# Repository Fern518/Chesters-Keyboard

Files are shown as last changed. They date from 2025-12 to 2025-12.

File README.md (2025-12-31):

# Chester's Keyboard
A custom TKL keyboard built for the *Hack Club Blueprint program*.

It functions as a miniature media dashboard: the display shows the current track (TO BE IMPLEMENTED), the knob controls volume, and the six keys can be bound to any shortcut.

## The Keyboard
Everything fits together using 4 M3 Bolts and Heatset inserts, one in each corner. 

It has 2 separate printed pieces. The base, where the PCB sits, and the top cover, which protects the PCB.

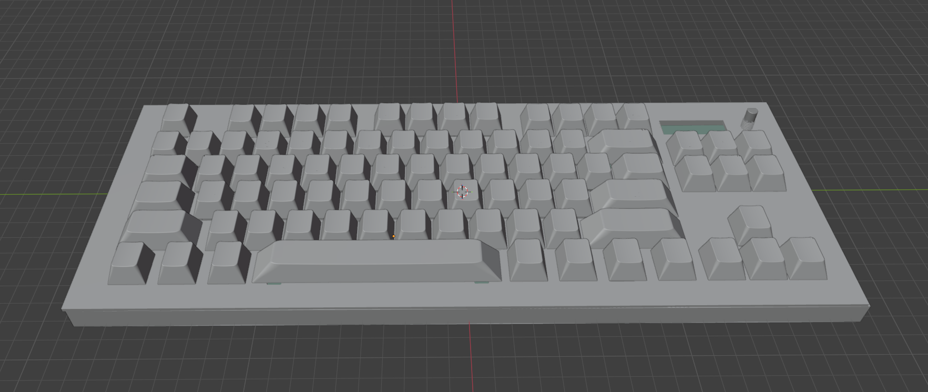
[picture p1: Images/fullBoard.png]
fullBoard

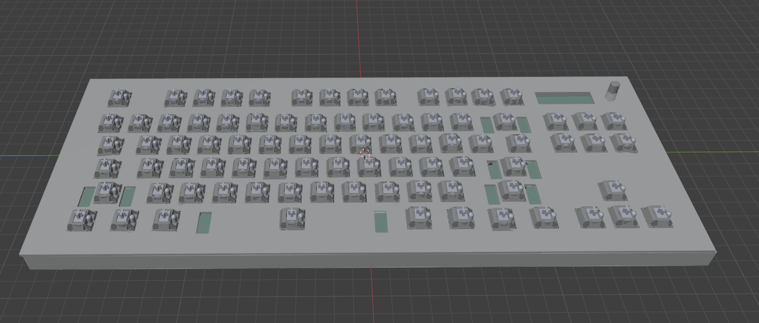
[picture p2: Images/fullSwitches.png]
fullSwitches

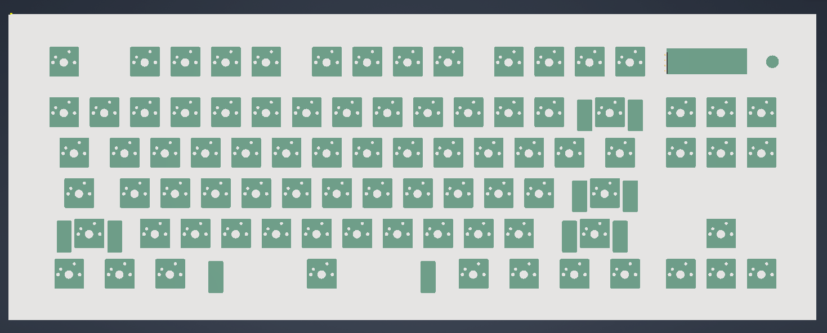
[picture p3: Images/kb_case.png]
fullCase

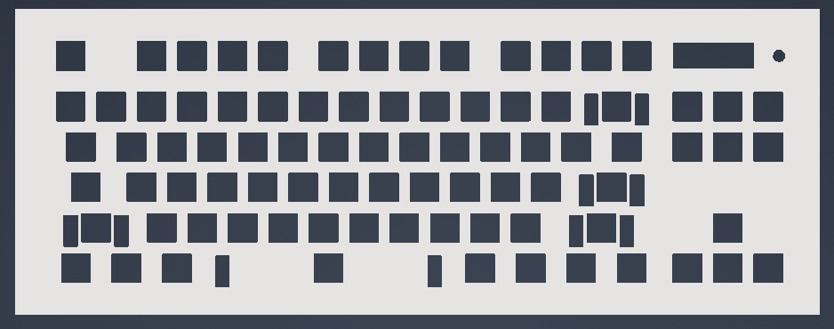
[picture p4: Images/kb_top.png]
caseTop

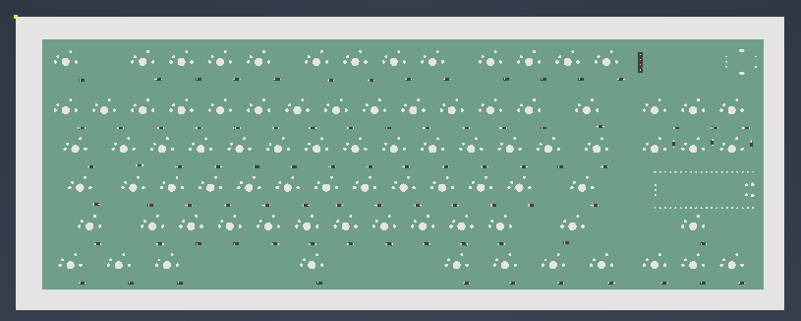
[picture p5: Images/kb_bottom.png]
caseBottom

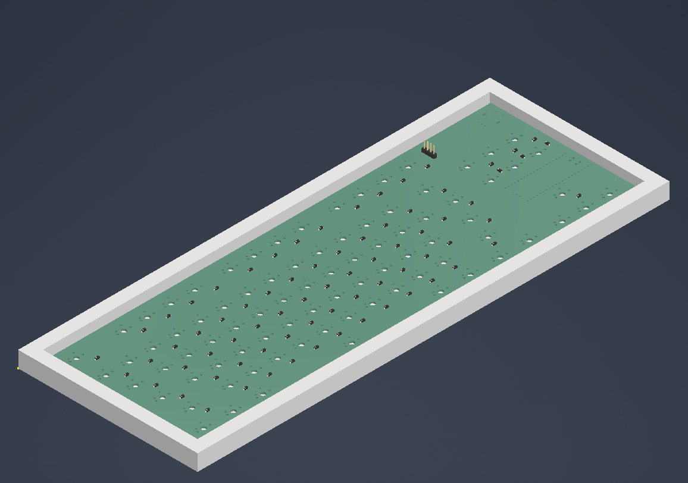
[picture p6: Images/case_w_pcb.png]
caseWithPCB


## PCB
My PCB was designed in KiCad. The rPi Pico is mounted on the bottom of the PCB between the home keys and arrow keys to make it as compact as possible.

Schematic:
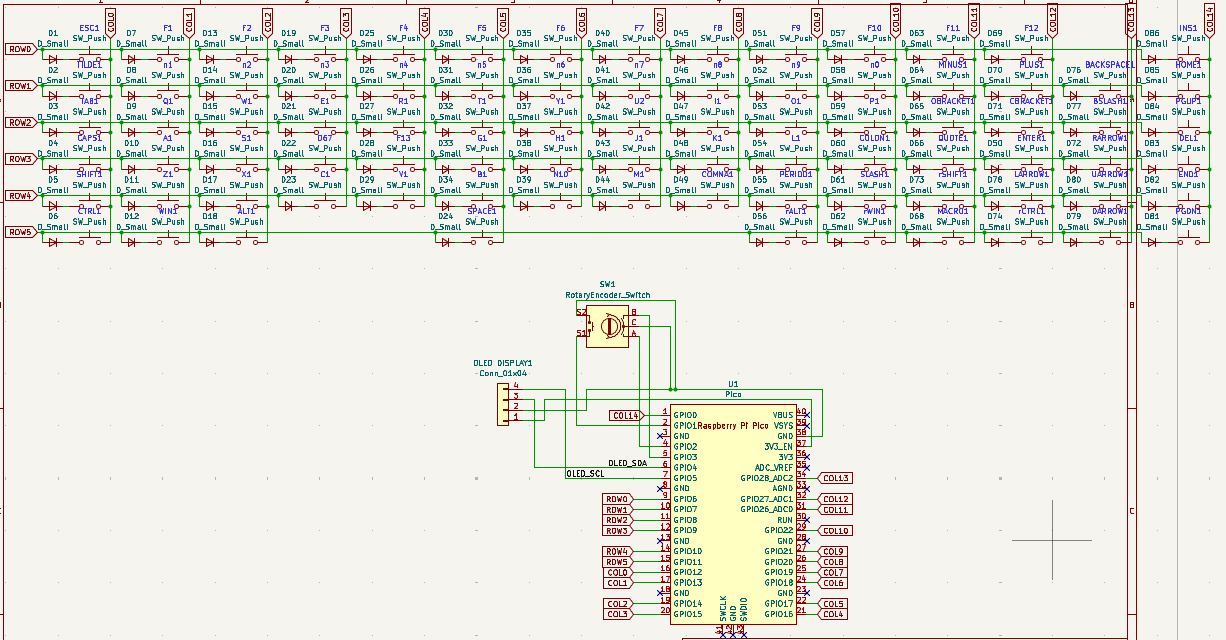
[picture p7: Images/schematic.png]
schematic


PCB:
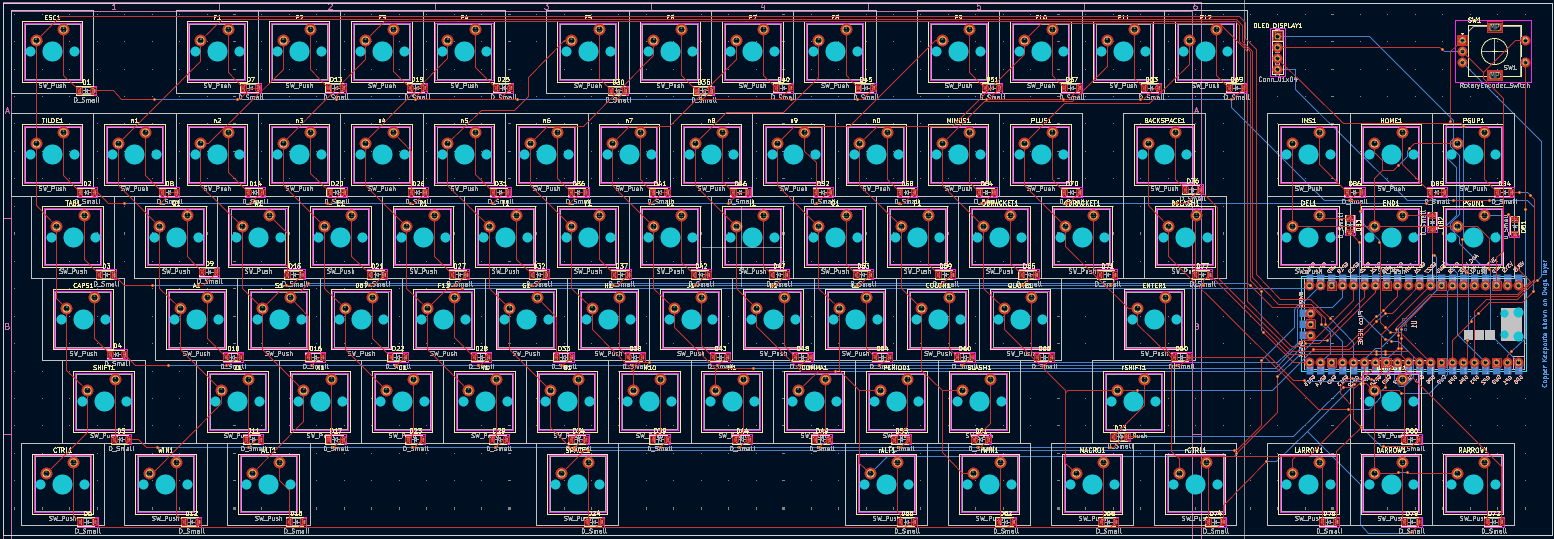
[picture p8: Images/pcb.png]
pcb


## BOM:
- 1x Case 
- 1x [Raspberry Pi Pico 2W](https://www.adafruit.com/pico?src=raspberrypi)
- 1x [0.91" 128x32 OLED Display](https://www.addicore.com/products/oled-display-128x32-0-91in-monochrome?variant=45759649120573)
- 1x [1N4148 Diodes - 100 Pack](https://www.adafruit.com/product/5099)
- 1x [EC11 Rotary Encoder](https://www.aliexpress.us/item/3256805924910339.html)
- 1x PCB (gerber files in pcb/)
- 89x [Cherry MX Switches](https://a.co/d/hjQgWfm)
- 89x [Keycaps](https://mechanicalkeyboards.com/products/tai-hao-104-key-pbt-double-shot-keycap-set-dark-greyblack)
- 1x [Keycap Stabilizers pack](https://divinikey.com/products/aeboards-staebies-v2-stabilizers?variant=40005101355073)
- 1x [Adafruit MCP23017 I2C GPIO Expander Breakout](https://www.adafruit.com/product/5346)
- 4x M3x5x4 Heatset inserts
- 4x M3x16mm SHCS Bolts

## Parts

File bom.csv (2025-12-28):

Parts: | Link | Price | Final
EC11 encoder with push switch | https://www.aliexpress.us/item/3256805924910339.html?src=google | $3 | $92.45
rPi Pico Microcontroller | https://www.adafruit.com/pico?src=raspberrypi | $5.00
1N4148 Diodes - 100 Pack | https://www.adafruit.com/product/5099 | $4.95
SSD1306 128×32 0.91' OLED | https://www.addicore.com/products/oled-display-128x32-0-91in-monochrome?variant=45759649120573 | $5.55
Keycaps | https://mechanicalkeyboards.com/products/tai-hao-104-key-pbt-double-shot-keycap-set-dark-greyblack | $28
Stabilizers | https://divinikey.com/products/aeboards-staebies-v2-stabilizers?variant=40005101355073 | $20
Adafruit MCP23017 I2C GPIO Expander Breakout | https://www.adafruit.com/product/5346 | $5.95
Switches | https://www.amazon.com/Gateron-KS-3X1-Compatible-Mechanical-Keyboard/dp/B0D17H6QFN | $20

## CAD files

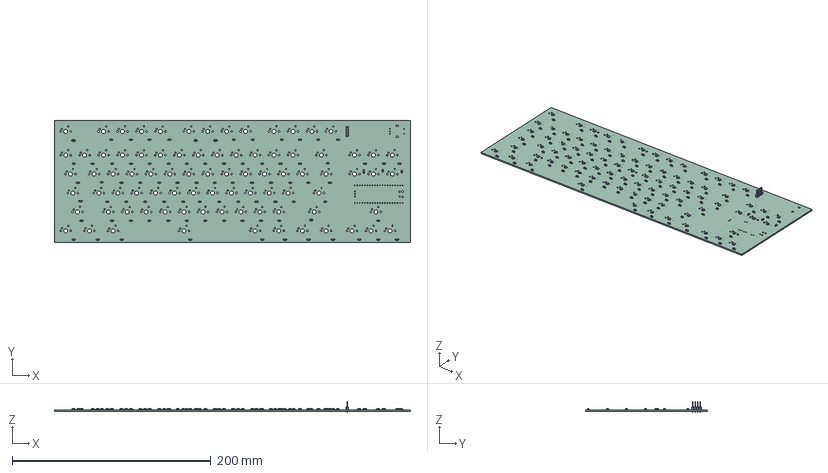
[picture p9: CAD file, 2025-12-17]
CAD/pcb3.step
358.1 x 123.2 x 11.5 mm
D_SOD-123 x 84
PinHeader_1x04_P2.54mm_Vertical
Pico
keyboard_PCB

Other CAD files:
CAD/pcb5.step
CAD/pcb4.step
CAD/pcb2.step
CAD/pcb.step
CAD/Assembly1.iam
CAD/Keyboard-bottom.ipt
CAD/Keyboard-top.ipt
CAD/OldVersions/Assembly1.0004.iam
CAD/OldVersions/Keyboard-bottom.0001.ipt
CAD/OldVersions/Keyboard-top.0006.ipt
CAD/pcb/pcb/pcb.ipt
CAD/pcb5/pcb5/pcb5.ipt
PCB/KiCad-RP-Pico-main/SketchUp Model/Pico.skp
PCB/keyboard/keyboard/keyboard.ipt

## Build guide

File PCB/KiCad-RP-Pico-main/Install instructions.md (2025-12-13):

# Install instructions

## 1. Copy the files locally

Copy the `RP-Pico Libraries` folder wherever you like on your computer.

## 2. Install the Raspberry Pi Pico board schema symbol

Use the `KiCad | Preferences | Manage Symbol Libraries...` command to manage the symbol library:



then select the global tab and click on the folder button:



navigate to the `RP-Pico Libraries` folder, select the `MCU_RaspberryPi_and_Boards.kicad_sym` file and open it:



et voilà, the first step is completed:



You can now close the symbol libraries manager window.

## 3. Install the Raspberry Pi Pico board footprint

You can use a similar approach to add the footprint to the footprint libraries manager, but I've found some issues that I've solved using the footprint editor, so here are the steps I suggest you to follow:

Open the footprint editor



wait for the footprints to load... then use the `File | Add Library` command:



confirm the `Global` choice:



and select the `MCU_RaspberriPi_and_Boards.pretty` folder (yes, the folder represent a footprint library on KiCad):



Now the library is installed on KiCad with the Raspberry Pi Pico footprint (double click on it to see it on the editor pane):



Don't close the windows as the next step start from here.

## 4. Install the Raspberry Pi Pico board footprint 3D visual

If not already open, open the the footprint editor

symbol library manager

double click on the `RPi_Pico_SMD_TH` footprint from the `MCU_RaspberriPi_and_Boards` library and then click on the `Footprint properties` icon:



In the footprint properties window, first select the `3D Settings` tab. Please note that the preview shows only the PCB board with the footprint added on step 3, without any 3D representation of the Raspberry Pi Pico board. Now click on the folder icon to add the 3D model:



Navigate to the `RP-Pico Libraries` folder, select the `Pico.wrl` file and wait until the model is shown in the right panel, then confirm with OK:



The model is already scaled and translated to match the footprint:



now close the `Footprint Properties` window, and the `Footprint Editor`, obviously saving the changes.

## Conclusion

Now that you've installed the schema and footprint and added the 3D model to the footprint, you can use the Raspberry Pi Pico board on your KiCad projects.

I've also added a test KiCad Project on the `Test` folder, that you can use to see an example of it.

Have fun!

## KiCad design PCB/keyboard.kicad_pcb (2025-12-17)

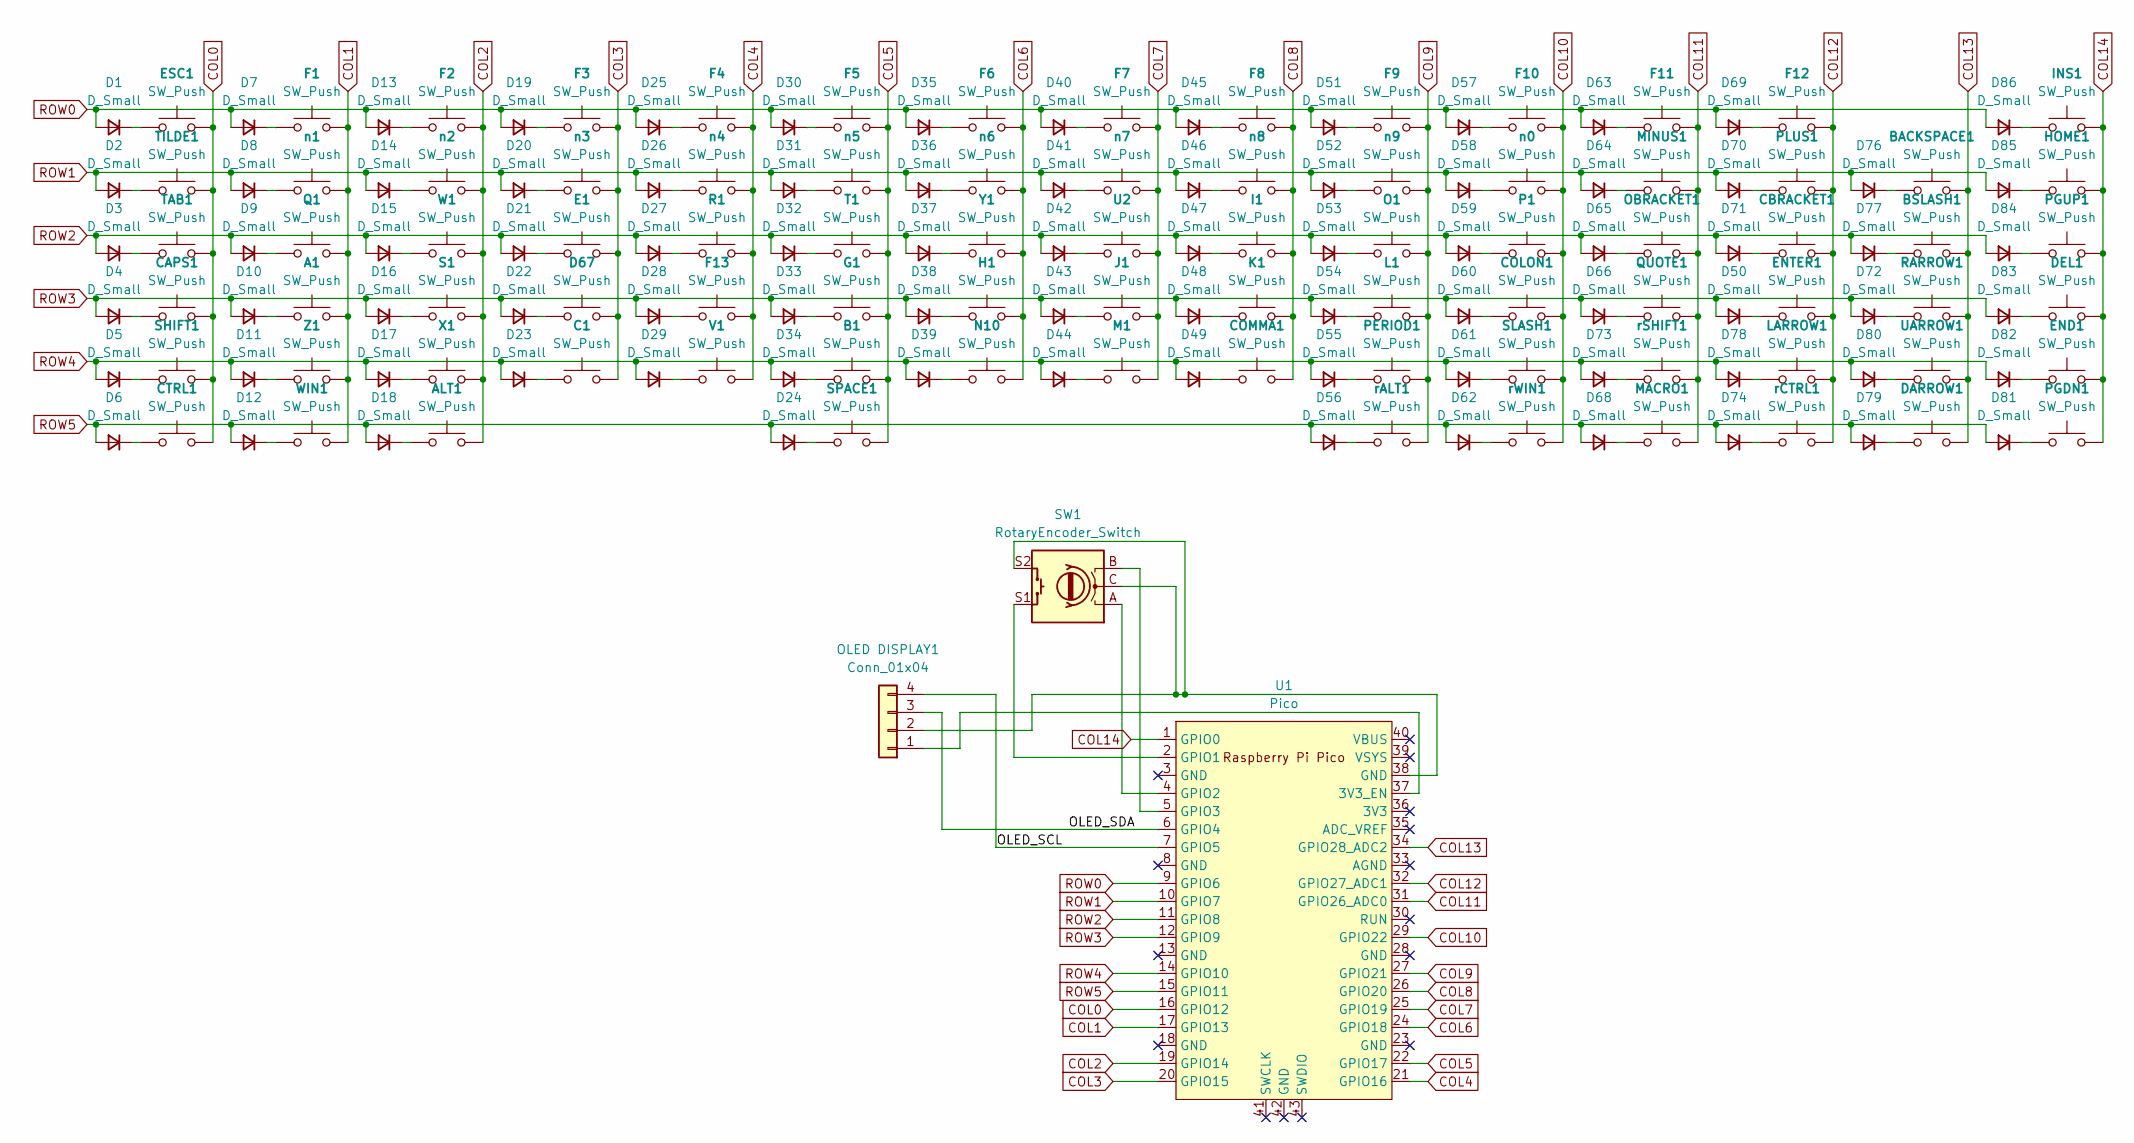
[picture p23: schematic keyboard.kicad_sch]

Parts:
A1: SW_Push; SW_Cherry_MX_1.00u_PCB
ALT1: SW_Push; SW_Cherry_MX_1.00u_PCB
B1: SW_Push; SW_Cherry_MX_1.00u_PCB
BACKSPACE1: SW_Push; SW_Cherry_MX_1.00u_PCB
BSLASH1: SW_Push; SW_Cherry_MX_1.00u_PCB
C1: SW_Push; SW_Cherry_MX_1.00u_PCB
CAPS1: SW_Push; SW_Cherry_MX_1.00u_PCB
CBRACKET1: SW_Push; SW_Cherry_MX_1.00u_PCB
COLON1: SW_Push; SW_Cherry_MX_1.00u_PCB
COMMA1: SW_Push; SW_Cherry_MX_1.00u_PCB
CTRL1: SW_Push; SW_Cherry_MX_1.00u_PCB
D1, D2, D3, D4, D5, D6, D7, D8, D9, D10, D11, D12, D13, D14, D15, D16, D17, D18, D19, D20, D21, D22, D23, D24, D25, D26, D27, D28, D29, D30, D31, D32, D33, D34, D35, D36, D37, D38, D39, D40, D41, D42, D43, D44, D45, D46, D47, D48, D49, D50, D51, D52, D53, D54, D55, D56, D57, D58, D59, D60, D61, D62, D63, D64, D65, D66, D68, D69, D70, D71, D72, D73, D74, D76, D77, D78, D79, D80, D81, D82, D83, D84, D85, D86: D_Small; D_SOD-123
D67: SW_Push; SW_Cherry_MX_1.00u_PCB
DARROW1: SW_Push; SW_Cherry_MX_1.00u_PCB
DEL1: SW_Push; SW_Cherry_MX_1.00u_PCB
E1: SW_Push; SW_Cherry_MX_1.00u_PCB
END1: SW_Push; SW_Cherry_MX_1.00u_PCB
ENTER1: SW_Push; SW_Cherry_MX_1.00u_PCB
ESC1: SW_Push; SW_Cherry_MX_1.00u_PCB
F1, F2, F3, F4, F5, F6, F7, F8, F9, F10, F11, F12, F13: SW_Push; SW_Cherry_MX_1.00u_PCB
G1: SW_Push; SW_Cherry_MX_1.00u_PCB
H1: SW_Push; SW_Cherry_MX_1.00u_PCB
HOME1: SW_Push; SW_Cherry_MX_1.00u_PCB
I1: SW_Push; SW_Cherry_MX_1.00u_PCB
INS1: SW_Push; SW_Cherry_MX_1.00u_PCB
J1: SW_Push; SW_Cherry_MX_1.00u_PCB
K1: SW_Push; SW_Cherry_MX_1.00u_PCB
L1: SW_Push; SW_Cherry_MX_1.00u_PCB
LARROW1: SW_Push; SW_Cherry_MX_1.00u_PCB
M1: SW_Push; SW_Cherry_MX_1.00u_PCB
MACRO1: SW_Push; SW_Cherry_MX_1.00u_PCB
MINUS1: SW_Push; SW_Cherry_MX_1.00u_PCB
N10: SW_Push; SW_Cherry_MX_1.00u_PCB
O1: SW_Push; SW_Cherry_MX_1.00u_PCB
OBRACKET1: SW_Push; SW_Cherry_MX_1.00u_PCB
OLED DISPLAY1: Conn_01x04; PinHeader_1x04_P2.54mm_Vertical
P1: SW_Push; SW_Cherry_MX_1.00u_PCB
PERIOD1: SW_Push; SW_Cherry_MX_1.00u_PCB
PGDN1: SW_Push; SW_Cherry_MX_1.00u_PCB
PGUP1: SW_Push; SW_Cherry_MX_1.00u_PCB
PLUS1: SW_Push; SW_Cherry_MX_1.00u_PCB
Q1: SW_Push; SW_Cherry_MX_1.00u_PCB
QUOTE1: SW_Push; SW_Cherry_MX_1.00u_PCB
R1: SW_Push; SW_Cherry_MX_1.00u_PCB
RARROW1: SW_Push; SW_Cherry_MX_1.00u_PCB
S1: SW_Push; SW_Cherry_MX_1.00u_PCB
SHIFT1: SW_Push; SW_Cherry_MX_1.00u_PCB
SLASH1: SW_Push; SW_Cherry_MX_1.00u_PCB
SPACE1: SW_Push; SW_Cherry_MX_1.00u_PCB
SW1: RotaryEncoder_Switch; RotaryEncoder_Alps_EC11E-Switch_Vertical_H20mm
T1: SW_Push; SW_Cherry_MX_1.00u_PCB
TAB1: SW_Push; SW_Cherry_MX_1.00u_PCB
TILDE1: SW_Push; SW_Cherry_MX_1.00u_PCB
U1: Pico; RPi_Pico_SMD_TH
U2: SW_Push; SW_Cherry_MX_1.00u_PCB
UARROW1: SW_Push; SW_Cherry_MX_1.00u_PCB
V1: SW_Push; SW_Cherry_MX_1.00u_PCB
W1: SW_Push; SW_Cherry_MX_1.00u_PCB
WIN1: SW_Push; SW_Cherry_MX_1.00u_PCB
X1: SW_Push; SW_Cherry_MX_1.00u_PCB
Y1: SW_Push; SW_Cherry_MX_1.00u_PCB
Z1: SW_Push; SW_Cherry_MX_1.00u_PCB
n0, n1, n2, n3, n4, n5, n6, n7, n8, n9: SW_Push; SW_Cherry_MX_1.00u_PCB
rALT1: SW_Push; SW_Cherry_MX_1.00u_PCB
rCTRL1: SW_Push; SW_Cherry_MX_1.00u_PCB
rSHIFT1: SW_Push; SW_Cherry_MX_1.00u_PCB
rWIN1: SW_Push; SW_Cherry_MX_1.00u_PCB

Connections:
/OLED_SCL: OLED DISPLAY1.4, U1.7 (GPIO5)
/OLED_SDA: OLED DISPLAY1.3, U1.6 (GPIO4)
COL0: CAPS1.2, CTRL1.2, ESC1.2, SHIFT1.2, TAB1.2, TILDE1.2, U1.16 (GPIO12)
COL1: A1.2, F1.2, Q1.2, U1.17 (GPIO13), WIN1.2, Z1.2, n1.2
COL2: ALT1.2, F2.2, S1.2, U1.19 (GPIO14), W1.2, X1.2, n2.2
COL3: C1.2, D67.2, E1.2, F3.2, U1.20 (GPIO15), n3.2
COL4: F4.2, F13.2, R1.2, U1.21 (GPIO16), V1.2, n4.2
COL5: B1.2, F5.2, G1.2, SPACE1.2, T1.2, U1.22 (GPIO17), n5.2
COL6: F6.2, H1.2, N10.2, U1.24 (GPIO18), Y1.2, n6.2
COL7: F7.2, J1.2, M1.2, U1.25 (GPIO19), U2.2, n7.2
COL8: COMMA1.2, F8.2, I1.2, K1.2, U1.26 (GPIO20), n8.2
COL9: F9.2, L1.2, O1.2, PERIOD1.2, U1.27 (GPIO21), n9.2, rALT1.2
COL10: COLON1.2, F10.2, P1.2, SLASH1.2, U1.29 (GPIO22), n0.2, rWIN1.2
COL11: F11.2, MACRO1.2, MINUS1.2, OBRACKET1.2, QUOTE1.2, U1.31 (GPIO26_ADC0), rSHIFT1.2
COL12: CBRACKET1.2, ENTER1.2, F12.2, LARROW1.2, PLUS1.2, U1.32 (GPIO27_ADC1), rCTRL1.2
COL13: BACKSPACE1.2, BSLASH1.2, DARROW1.2, RARROW1.2, U1.34 (GPIO28_ADC2), UARROW1.2
COL14: DEL1.2, END1.2, HOME1.2, INS1.2, PGDN1.2, PGUP1.2, U1.1 (GPIO0)
unnamed: D1.1 (K), ESC1.1
unnamed: D2.1 (K), TILDE1.1
unnamed: D3.1 (K), TAB1.1
unnamed: CAPS1.1, D4.1 (K)
unnamed: D5.1 (K), SHIFT1.1
unnamed: CTRL1.1, D6.1 (K)
unnamed: D7.1 (K), F1.1
unnamed: D8.1 (K), n1.1
unnamed: D9.1 (K), Q1.1
unnamed: A1.1, D10.1 (K)
unnamed: D11.1 (K), Z1.1
unnamed: D12.1 (K), WIN1.1
unnamed: D13.1 (K), F2.1
unnamed: D14.1 (K), n2.1
unnamed: D15.1 (K), W1.1
unnamed: D16.1 (K), S1.1
unnamed: D17.1 (K), X1.1
unnamed: ALT1.1, D18.1 (K)
unnamed: D19.1 (K), F3.1
unnamed: D20.1 (K), n3.1
unnamed: D21.1 (K), E1.1
unnamed: D22.1 (K), D67.1
unnamed: C1.1, D23.1 (K)
unnamed: D24.1 (K), SPACE1.1
unnamed: D25.1 (K), F4.1
unnamed: D26.1 (K), n4.1
unnamed: D27.1 (K), R1.1
unnamed: D28.1 (K), F13.1
unnamed: D29.1 (K), V1.1
unnamed: D30.1 (K), F5.1
unnamed: D31.1 (K), n5.1
unnamed: D32.1 (K), T1.1
unnamed: D33.1 (K), G1.1
unnamed: B1.1, D34.1 (K)
unnamed: D35.1 (K), F6.1
unnamed: D36.1 (K), n6.1
unnamed: D37.1 (K), Y1.1
unnamed: D38.1 (K), H1.1
unnamed: D39.1 (K), N10.1
unnamed: D40.1 (K), F7.1
unnamed: D41.1 (K), n7.1
unnamed: D42.1 (K), U2.1
unnamed: D43.1 (K), J1.1
unnamed: D44.1 (K), M1.1
unnamed: D45.1 (K), F8.1
unnamed: D46.1 (K), n8.1
unnamed: D47.1 (K), I1.1
unnamed: D48.1 (K), K1.1
unnamed: COMMA1.1, D49.1 (K)
unnamed: D50.1 (K), ENTER1.1
unnamed: D51.1 (K), F9.1
unnamed: D52.1 (K), n9.1
unnamed: D53.1 (K), O1.1
unnamed: D54.1 (K), L1.1
unnamed: D55.1 (K), PERIOD1.1
unnamed: D56.1 (K), rALT1.1
unnamed: D57.1 (K), F10.1
unnamed: D58.1 (K), n0.1
unnamed: D59.1 (K), P1.1
unnamed: COLON1.1, D60.1 (K)
unnamed: D61.1 (K), SLASH1.1
unnamed: D62.1 (K), rWIN1.1
unnamed: D63.1 (K), F11.1
unnamed: D64.1 (K), MINUS1.1
unnamed: D65.1 (K), OBRACKET1.1
unnamed: D66.1 (K), QUOTE1.1
unnamed: D68.1 (K), MACRO1.1
unnamed: D69.1 (K), F12.1
unnamed: D70.1 (K), PLUS1.1
unnamed: CBRACKET1.1, D71.1 (K)
unnamed: D72.1 (K), RARROW1.1
unnamed: D73.1 (K), rSHIFT1.1
unnamed: D74.1 (K), rCTRL1.1
unnamed: BACKSPACE1.1, D76.1 (K)
unnamed: BSLASH1.1, D77.1 (K)
unnamed: D78.1 (K), LARROW1.1
unnamed: D79.1 (K), DARROW1.1
unnamed: D80.1 (K), UARROW1.1
unnamed: D81.1 (K), PGDN1.1
unnamed: D82.1 (K), END1.1
unnamed: D83.1 (K), DEL1.1
unnamed: D84.1 (K), PGUP1.1
unnamed: D85.1 (K), HOME1.1
unnamed: D86.1 (K), INS1.1
unnamed: OLED DISPLAY1.1, U1.37 (3V3_EN)
unnamed: OLED DISPLAY1.2, SW1.C, SW1.S2, U1.38 (GND)
unnamed: SW1.S1, U1.2 (GPIO1)
unnamed: SW1.A, U1.4 (GPIO2)
unnamed: SW1.B, U1.5 (GPIO3)
ROW0: D1.2 (A), D7.2 (A), D13.2 (A), D19.2 (A), D25.2 (A), D30.2 (A), D35.2 (A), D40.2 (A), D45.2 (A), D51.2 (A), D57.2 (A), D63.2 (A), D69.2 (A), D86.2 (A), U1.9 (GPIO6)
ROW1: D2.2 (A), D8.2 (A), D14.2 (A), D20.2 (A), D26.2 (A), D31.2 (A), D36.2 (A), D41.2 (A), D46.2 (A), D52.2 (A), D58.2 (A), D64.2 (A), D70.2 (A), D76.2 (A), D85.2 (A), U1.10 (GPIO7)
ROW2: D3.2 (A), D9.2 (A), D15.2 (A), D21.2 (A), D27.2 (A), D32.2 (A), D37.2 (A), D42.2 (A), D47.2 (A), D53.2 (A), D59.2 (A), D65.2 (A), D71.2 (A), D77.2 (A), D84.2 (A), U1.11 (GPIO8)
ROW3: D4.2 (A), D10.2 (A), D16.2 (A), D22.2 (A), D28.2 (A), D33.2 (A), D38.2 (A), D43.2 (A), D48.2 (A), D50.2 (A), D54.2 (A), D60.2 (A), D66.2 (A), D72.2 (A), D83.2 (A), U1.12 (GPIO9)
ROW4: D5.2 (A), D11.2 (A), D17.2 (A), D23.2 (A), D29.2 (A), D34.2 (A), D39.2 (A), D44.2 (A), D49.2 (A), D55.2 (A), D61.2 (A), D73.2 (A), D78.2 (A), D80.2 (A), D82.2 (A), U1.14 (GPIO10)
ROW5: D6.2 (A), D12.2 (A), D18.2 (A), D24.2 (A), D56.2 (A), D62.2 (A), D68.2 (A), D74.2 (A), D79.2 (A), D81.2 (A), U1.15 (GPIO11)

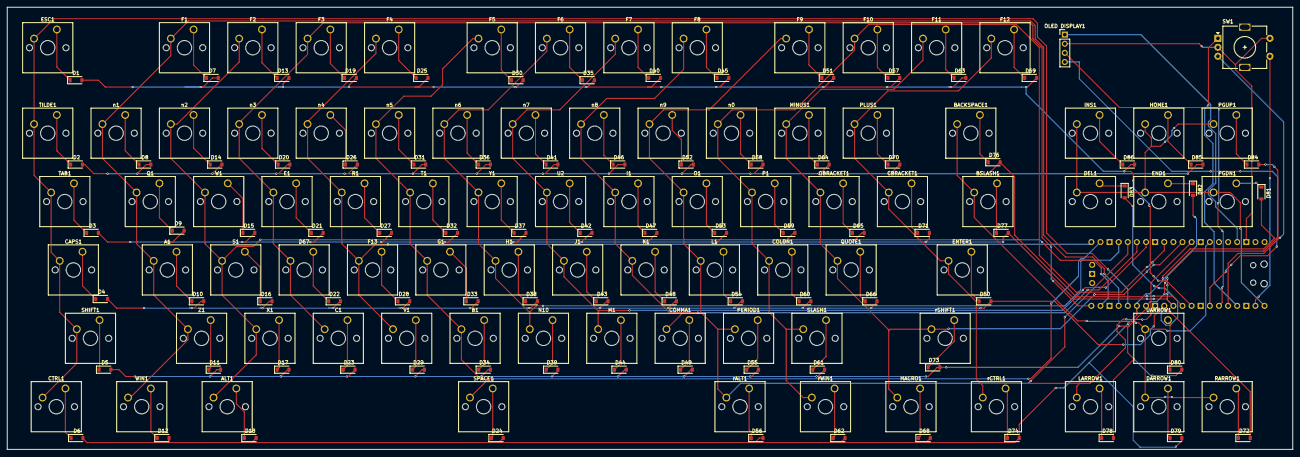
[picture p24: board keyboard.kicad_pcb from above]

Board: 2 copper layers, 358.1 x 123.2 mm, 171 parts (1 on the bottom side), 112 nets.

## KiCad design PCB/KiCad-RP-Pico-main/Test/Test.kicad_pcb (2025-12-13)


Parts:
J1, J2: Conn_01x20; PinSocket_1x20_P1.00mm_Vertical
J3: Conn_01x03; PinSocket_1x03_P1.00mm_Vertical
U1: Pico; RPi_Pico_SMD_TH

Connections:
GND: J1.3, J1.8, J1.13, J1.18, J2.3, J2.13, J2.18, J3.2, U1.3 (GND), U1.8 (GND), U1.13 (GND), U1.18 (GND), U1.23 (GND), U1.28 (GND), U1.38 (GND), U1.42 (GND)
unnamed: J1.1, U1.1 (GPIO0)
unnamed: J1.2, U1.2 (GPIO1)
unnamed: J1.4, U1.4 (GPIO2)
unnamed: J1.5, U1.5 (GPIO3)
unnamed: J1.6, U1.6 (GPIO4)
unnamed: J1.7, U1.7 (GPIO5)
unnamed: J1.9, U1.9 (GPIO6)
unnamed: J1.10, U1.10 (GPIO7)
unnamed: J1.11, U1.11 (GPIO8)
unnamed: J1.12, U1.12 (GPIO9)
unnamed: J1.14, U1.14 (GPIO10)
unnamed: J1.15, U1.15 (GPIO11)
unnamed: J1.16, U1.16 (GPIO12)
unnamed: J1.17, U1.17 (GPIO13)
unnamed: J1.19, U1.19 (GPIO14)
unnamed: J1.20, U1.20 (GPIO15)
unnamed: J2.1, U1.40 (VBUS)
unnamed: J2.2, U1.39 (VSYS)
unnamed: J2.4, U1.37 (3V3_EN)
unnamed: J2.5, U1.36 (3V3)
unnamed: J2.6, U1.35 (ADC_VREF)
unnamed: J2.7, U1.34 (GPIO28_ADC2)
unnamed: J2.8, U1.33 (AGND)
unnamed: J2.9, U1.32 (GPIO27_ADC1)
unnamed: J2.10, U1.31 (GPIO26_ADC0)
unnamed: J2.11, U1.30 (RUN)
unnamed: J2.12, U1.29 (GPIO22)
unnamed: J2.14, U1.27 (GPIO21)
unnamed: J2.15, U1.26 (GPIO20)
unnamed: J2.16, U1.25 (GPIO19)
unnamed: J2.17, U1.24 (GPIO18)
unnamed: J2.19, U1.22 (GPIO17)
unnamed: J2.20, U1.21 (GPIO16)
unnamed: J3.1, U1.43 (SWDIO)
unnamed: J3.3, U1.41 (SWCLK)


Board: 2 copper layers, 43.0 x 65.0 mm, 4 parts (0 on the bottom side), 36 nets.

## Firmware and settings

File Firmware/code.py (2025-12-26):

from kmk.kmk_keyboard import KMKKeyboard
from kmk.keys import KC
from kmk.scanners import DiodeOrientation
import board

keyboard = KMKKeyboard()

# Rows: ROW0..ROW5
keyboard.row_pins = (
    board.GP6,
    board.GP7,
    board.GP8,
    board.GP9,
    board.GP10,
    board.GP11,
)

# Cols: COL0..COL14
keyboard.col_pins = (
    board.GP12,  # COL0
    board.GP13,  # COL1
    board.GP14,  # COL2
    board.GP15,  # COL3
    board.GP16,  # COL4
    board.GP17,  # COL5
    board.GP18,  # COL6
    board.GP19,  # COL7
    board.GP20,  # COL8
    board.GP21,  # COL9
    board.GP22,  # COL10
    board.GP26,  # COL11
    board.GP27,  # COL12
    board.GP28,  # COL13
    board.GP0,   # COL14
)

keyboard.diode_orientation = DiodeOrientation.ROW2COL

keyboard.keymap = [[
    # Row 0 (15)
    KC.ESC, KC.TAB, KC.BSPC, KC.LSFT, KC.LCTL, KC.LALT, KC.LGUI, KC.RGUI, KC.RALT, KC.RCTL, KC.RSFT, KC.NO, KC.NO, KC.NO, KC.NO,
    # Row 1 (15)
    KC.F1, KC.F2, KC.F3, KC.F4, KC.F5, KC.F6, KC.F7, KC.F8, KC.F9, KC.F10, KC.F11, KC.F12, KC.NO, KC.NO, KC.NO,
    # Row 2 (15)
    KC.N1, KC.N2, KC.N3, KC.N4, KC.N5, KC.N6, KC.N7, KC.N8, KC.N9, KC.N0, KC.NO, KC.NO, KC.NO, KC.NO, KC.NO,
    # Row 3 (15)
    KC.Q, KC.W, KC.E, KC.R, KC.T, KC.Y, KC.U, KC.I, KC.O, KC.P, KC.LBRC, KC.RBRC, KC.BSLS, KC.MINS, KC.EQL,
    # Row 4 (15)
    KC.A, KC.S, KC.D, KC.F, KC.G, KC.H, KC.J, KC.K, KC.L, KC.SCLN, KC.QUOT, KC.ENT, KC.NO, KC.NO, KC.NO,
    # Row 5 (15)
    KC.Z, KC.X, KC.C, KC.V, KC.B, KC.N, KC.M, KC.COMM, KC.DOT, KC.SLSH, KC.SPC, KC.NO, KC.NO, KC.NO, KC.NO,


]]

if __name__ == "__main__":
    keyboard.go()

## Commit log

2025-12-13 Created PCB Files
    [Pico.skp, Test.kicad_pcb, Test.kicad_sch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]
2025-12-13 Major PCB Updates (Read desc.)
    Since the last update, I designed an ANSI TKL based keyboard layout schematic in KiCad using a Raspberry Pi Pico 2W as the controller. I started by selecting and labeling usable GPIO pins on the Pico and assigning them to six row lines (ROW0–ROW5) and fifteen column lines (COL0–COL14). I had some issues figuring out diode orientation, but I got it eventually. I then expanded it into a full ANSI-based TKL layout.
    [keyboard.kicad_sch]
2025-12-13 Fixed a ton of ERC issues
    [keyboard.kicad_sch]
2025-12-13 Fixed more issues
    Had to add weird number annotations to the end of each key to stop the ERC whining
    [keyboard.kicad_sch]
2025-12-13 Reorganised keys to fit better
    [keyboard.kicad_sch]
2025-12-13 Layed out key matrix
    This was extremely tedious and time consuming. I had to physically lay out all the keys in their correct positions on the PCB. I still haven't laid out the diodes, so that comes next. So far, I'm pretty happy with the layout I've achieved!
    [keyboard.kicad_pcb, keyboard.kicad_sch]
2025-12-13 Got rid of extra unnecessary key
    [keyboard.kicad_pcb, keyboard.kicad_sch]
2025-12-13 Moved diodes into position
    [keyboard.kicad_pcb]
2025-12-14 Wired rows and columns together
    I pretty much did the process of hooking each key and diode up to each row and collumn. I haven't attached them to the Raspberrry Pi Pico 2W yet, but that will come next.
    [keyboard.kicad_pcb]
2025-12-14 All rows connected
    [keyboard.kicad_pcb]
2025-12-14 Completed PCB
    [keyboard.kicad_pcb]
2025-12-14 Started work on case
    [Assembly1.iam, Keyboard-bottom.0001.ipt, Keyboard-bottom.ipt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]
2025-12-15 Fixed a bunch of key spacing issues
    I put in some more work on the case, then realized that if the keys are too close on the pcb, the keycaps wont fit (i was worried about larger keys like shift, and how far they should be spaced from the letter keys). i did some googling, and realized that there is an actual grid system for this, and I had completely ignored this when placing keys on my PCB. I had to go back over every key and measure the correct distances, then adjust the switch position accordingly. It was a lot of tedious work, but it payed off. It would have sucked to order the PCB and have none of the keycaps fit.
    [keyboard.kicad_pcb]
2025-12-16 Added top cover and PCB Adjustments
    moved home and arrow keys left to fit the standard ANSI grid
    [Assembly1.0002.iam, Assembly1.iam, Keyboard-top.0003.ipt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]
2025-12-17 Redid PCB bottom two rows
    Fixed spacing issues and rewired nodes
    [Assembly1.0002.iam, Assembly1.0003.iam, Assembly1.iam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]
2025-12-19 Added keyboard top model and updated README
    [Assembly1.0003.iam, Assembly1.0004.iam, Assembly1.iam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]
2025-12-28 Added bom.csv and case with PCB image to readme
    [bom.csv]
2025-12-31 added full board renders and gerber .zip
    [keyboard-B_Cu.gbr, keyboard-B_Mask.gbr, keyboard-B_Paste.gbr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]
